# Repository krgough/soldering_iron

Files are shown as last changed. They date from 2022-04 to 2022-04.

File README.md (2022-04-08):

# soldering_iron

Schematic, PCB and Firmware for a temperature controlled soldering iron.   
Based on >> https://www.instructables.com/DIY-Digital-Soldering-Station/?utm_source=newsletter&utm_medium=email

## Design Notes
Soldering Iron has a 5 ohm heater coil and a PTC temperature sensor.  So we switch our source voltage (24v or less) via  a mosfet through the heater to operate the iron.  We measure the tip temperature via the PTC.

Wanted Temp Range = 500-24'C = 475 degree steps
10 bit ADC resolution = 5 v* (2^10 - 1) = 4.887mV/div

PTC Values are approx:
24'C = 50R
500'C = 215R

For the PTC we use a potential divider of 470R + PTC(approx 50R at 24'C).   This results in a voltage range of around 0.48v - 1.49v = 1v = 207 ADC steps.   Each ADC step is therefore equivalent to more than 1'C, so we would have missing temperature values.

To overcome that problem we use an opamp with a gain of 2.22
G = Rf/Ri + 1 = 3300/2700 + 1 = 2.22

24'C    = 0.48 * 2.22 = 1.06v
500'C = 1.57 * 2.22 = 3.49v

This gives a range of 2.25v or 497 ADC steps.

Note that Max Vout from LM358 is around 3v5 when running from 5v, so it's hard to get any more without introducing a level shift as well.  I did experiment with using the spare opamp as a unity gain buffer to put a non-zero voltage on the gain setting resistor that would normally be connected to ground - this seemed to create odd behaviour (output was not linear) so I abandoned that as the simple solution above seems to be close enough.

## Display
We use a 16x2 LCD with a I2C interface.  In my case I'm using an Adafruit module that was originally purchased for use with an rPi.

## Spare OpAmp
Terminated the device as a unity gain buffer with input set to mid rail.

## Adjustable SMPS
We power the device with 18-24v and then use the SMPS to regulate down to 5v for the control circuits and display.  Since the SMPS is adjustable I put a jumper in the output so that I can adjust the voltage with the rest of the circuit disconnected.

## Firmware
- We average the readings to try to reduce any noise for the control loop.
- Display refresh - we limit the refresh rate to once a second to stop and annoying flickering 
- Hysteresis - We have implemented some temperature hysteresis on the control loop to prevent rapid switching - it may not be required but it seems to be sensible to prevent any rapid oscillations.

## Protection/Safety Considerations (To be done - not yet implemented)
The Iron can reach 500'C or higher when left on continuously.  For safety I think it's worth having a couple of features...
- If the Arduino crashes with the MOSFET on then Iron can overheat.  Mitigation is to implement watchdog in Arduino so that a WD Reset will occur if the device locks out for some reason.  This is not entirely ideal - We could also have some external circuit like a monostable, so that we have to keep sending pulses to the monostable to enable the MOSFET, but this would require additional circuitry.
- Limit the max use time to x minutes.  Use a timer to turn the Iron to standby after a given time.  User needs to adjust the setpoint to make it come back on.  Iron shall start up in standby so that user interaction is required before the heater is turned on.   Suggest this is done by creating a new state variable "bool standby = 0".   Standby is disabled by a change of > 5'C on the setpoint.

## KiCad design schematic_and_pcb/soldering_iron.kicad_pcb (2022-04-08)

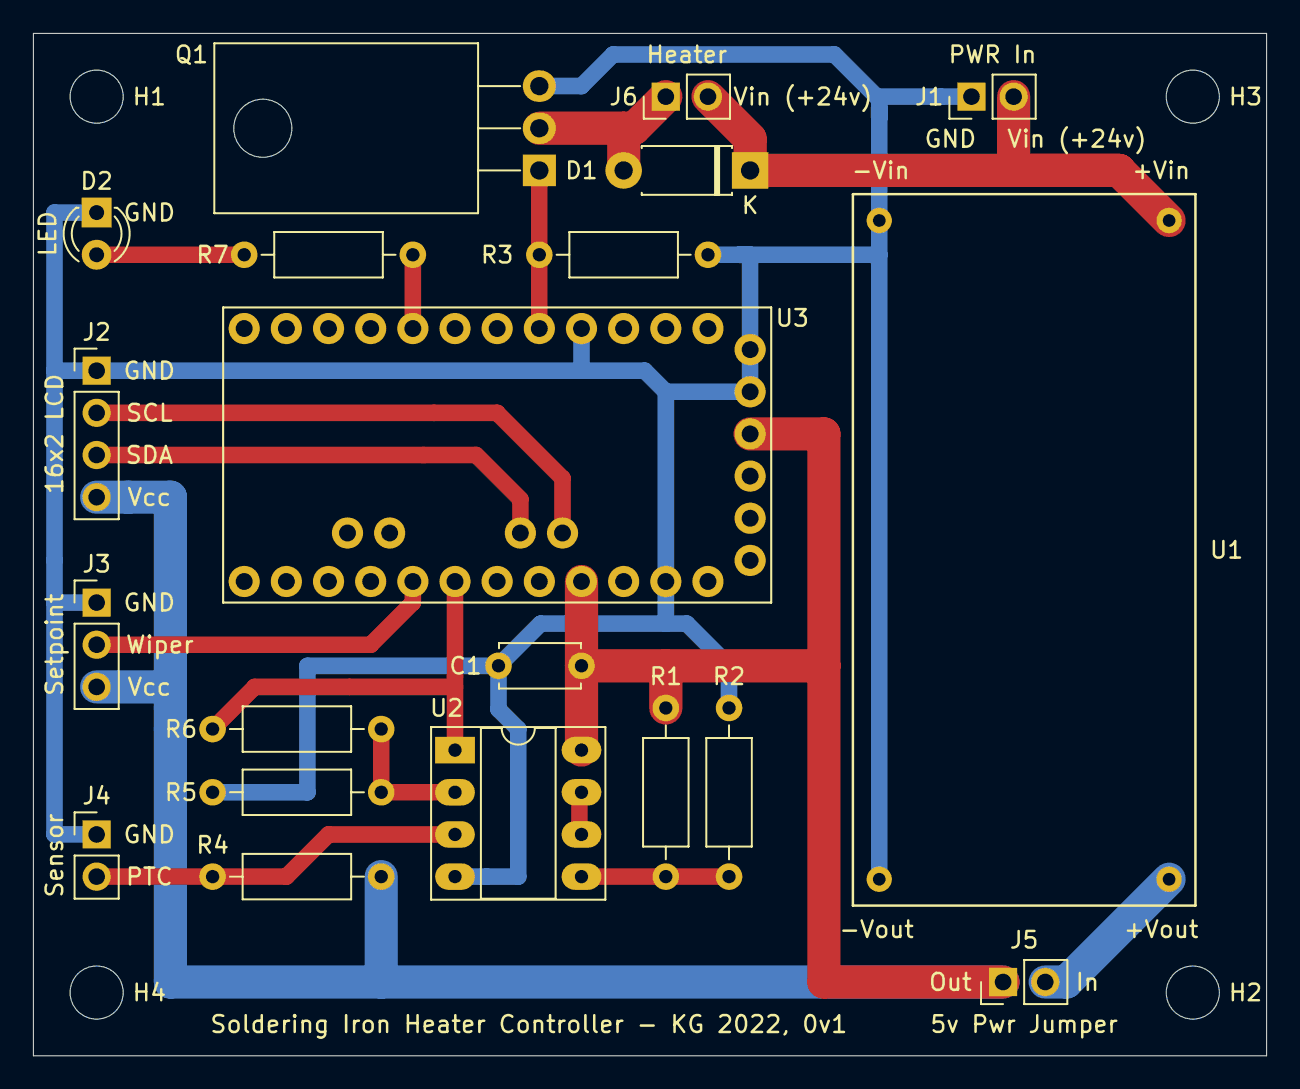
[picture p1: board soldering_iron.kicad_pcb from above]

Board: 2 copper layers, 74.3 x 61.6 mm, 24 parts (0 on the bottom side), 16 nets.

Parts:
C1: 100n; C_Disc_D4.7mm_W2.5mm_P5.00mm
D1: 1N4004; D_DO-41_SOD81_P7.62mm_Horizontal
D2: LED; LED_D3.0mm
H1, H2, H3, H4: MountingHole; MountingHole_3.2mm_M3
J1: PWR In; PinHeader_1x02_P2.54mm_Vertical
J2: 16x2 LCD; PinHeader_1x04_P2.54mm_Vertical
J3: Setpoint; PinHeader_1x03_P2.54mm_Vertical
J4: Sensor; PinHeader_1x02_P2.54mm_Vertical
J5: 5v Pwr Jumper; PinHeader_1x02_P2.54mm_Vertical
J6: Heater; PinHeader_1x02_P2.54mm_Vertical
Q1: IRLZ44N; TO-220-3_Horizontal_TabDown
R1, R2, R3: 10k; R_Axial_DIN0207_L6.3mm_D2.5mm_P10.16mm_Horizontal
R4: 470R; R_Axial_DIN0207_L6.3mm_D2.5mm_P10.16mm_Horizontal
R5: 2k7; R_Axial_DIN0207_L6.3mm_D2.5mm_P10.16mm_Horizontal
R6: 3k3; R_Axial_DIN0207_L6.3mm_D2.5mm_P10.16mm_Horizontal
R7: 1k; R_Axial_DIN0207_L6.3mm_D2.5mm_P10.16mm_Horizontal
U1: SMPS_24v_5v
U2: LM358; DIP-8_W7.62mm_Socket_LongPads
U3: ARDUINO_PRO_MINI; MODULE_ARDUINO_PRO_MINI

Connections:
+24v: D1.1, J1.2, J6.2, U1.4
GND: C1.2, D2.1, J1.1, J2.1, J3.1, J4.1, Q1.3, R2.2, R3.2, R5.2, U1.1, U1.2, U2.4, U3.JP1_5, U3.JP1_6, U3.JP6_2, U3.JP7_9
HEAT: Q1.1, R3.1, U3.JP7_8
unnamed: D1.2, J6.1, Q1.2
unnamed: D2.2, R7.1
unnamed: J5.2, U1.3
unnamed: R1.2, R2.1, U2.5
unnamed: R5.1, R6.2, U2.2
unnamed: R7.2, U3.JP7_5
unnamed: U2.6, U2.7
PTC: J4.2, R4.2, U2.3
PTC_SENSOR: R6.1, U2.1, U3.JP6_7
SCL: J2.2, U3.JP2_2
SDA: J2.3, U3.JP2_1
SETPOINT: J3.2, U3.JP6_8
VCC: C1.1, J2.4, J3.3, J5.1, R1.1, R4.1, U2.8, U3.JP1_4, U3.JP6_4

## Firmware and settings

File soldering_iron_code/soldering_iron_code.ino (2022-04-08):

/*********************
Temperature Controlled Solder Iron

- Read the temperature of the iron PTC sensor
- Read the setpoint potentiometer (scale this to a temperature)
- Turn the heater element on if cold, off if hot
- Show the setpoint and actual temperatures on a 16x2 LCD.

Iron temperature reading is scaled by a non-inverting opamp with gain=2.22 to give us a wider dynamic range of the ADC.
Readings were calibrated using a thermocouple attached to the iron tip

**********************/

// include the library code:
#include <Wire.h>
#include <Adafruit_RGBLCDShield.h>
#include <utility/Adafruit_MCP23017.h>

#define setpointPin A0
#define sensorPin A1
#define heaterPin 2
#define ledPin 5
#define minTemp 19
#define minADC 222       // 0.487 * Gain (2.22) / 4.88mV (ADC step size) = 221
#define maxTemp 500
#define maxADC 670      // 1.572 * 2.22 / 4.88mV = 715, 650
#define numReadings 3  // We average over 3 readings
#define hysteresis 5

int actualStore = 0;
int setpointStore = 0;
int actual = 0;
int setpoint = 0;
int lcdUpdate = 1000;       // LCD refresh rate (milliseconds)
int readCount = 0;
bool heat = 0;
unsigned long timeNow = 0;

// The shield uses the I2C SCL and SDA pins. On classic Arduinos
// this is Analog 4 and 5 so you can't use those for analogRead() anymore
// However, you can connect other I2C sensors to the I2C bus and share
// the I2C bus.
Adafruit_RGBLCDShield lcd = Adafruit_RGBLCDShield();

void update_screen(int temp, int preset) {
  //lcd.clear();
  char buf[16];

  // Show the measured temperature
  lcd.setCursor(0,0);
  sprintf(buf, "Actual: %3i%cC", temp, (char)223);
  lcd.print(buf);

  // Show the setpoint temperature
  lcd.setCursor(0,1);
  if (preset<=minTemp){
    sprintf(buf, "Preset: OFF");
  }
  else{
    sprintf(buf, "Preset: %3i%cC", preset, (char)223);
  }
  lcd.print(buf);
  
}

void setup() {

  // Make sure our heater and LED are off
  pinMode(heaterPin,OUTPUT);
  pinMode(ledPin,OUTPUT);
  pinMode(setpointPin,INPUT);
  pinMode(sensorPin,INPUT);
  digitalWrite(heaterPin, 0);
  digitalWrite(ledPin, 0);

  // set up the LCD's number of columns and rows: 
  lcd.begin(16, 2);
  lcd.print("    KG Rocks    ");
  lcd.setCursor(0,1);
  lcd.print("  Oh Yeah Baby  ");
  Serial.begin(115200);
  while (!Serial);
  Serial.println("Hello");
  delay(2000);
  lcd.clear();  
}


void loop() {

  // Read the preset and actual temperature values and scale to degrees centigrade
  // Average the readings
  if (readCount < numReadings){
    // Read and scale the analog values
    actualStore += analogRead(sensorPin);
    setpointStore += analogRead(setpointPin);
    readCount ++;
  } else {
    actual = map(int((actualStore / numReadings) + 0.5),minADC,maxADC,minTemp,maxTemp);
    setpoint = map(int((setpointStore / numReadings) + 0.5),0,1024,minTemp,maxTemp);
    //Serial.println(analogRead(sensorPin));
    actualStore = 0;
    setpointStore = 0;
    readCount = 0;
  }

//  actual = map(int(analogRead(sensorPin)), minADC, maxADC, minTemp, maxTemp);
//  setpoint = map(int(analogRead(setpointPin)), 0, 1024, minTemp, maxTemp);

  // Update the screen - this sum handles the millis rollover
  // Difference of unsigned long works for this
  if ((millis() - timeNow) > lcdUpdate){
    timeNow = millis();
    update_screen(actual, setpoint);
  }

  // Control the heater
  if (setpoint<=24){
    heat = 0;
    digitalWrite(ledPin,LOW);
    digitalWrite(heaterPin,LOW);
  }
  else if(heat==0){
    if (actual<=setpoint-hysteresis){
      heat = 1;
      digitalWrite(ledPin,HIGH);
      digitalWrite(heaterPin,HIGH);
      Serial.println("on");
    }
  }
  else if(heat==1){
    if (actual>setpoint){
      heat = 0;
      digitalWrite(ledPin,LOW);
      digitalWrite(heaterPin,LOW);
      Serial.println("off");
    }
  }  
}
